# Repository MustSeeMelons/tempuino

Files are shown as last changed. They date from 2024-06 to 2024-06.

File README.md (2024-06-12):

# Infrared temprature thing

Portable! Battery powered! Rechargable!

Programable with a generic FTDI module. It even has a cutout.

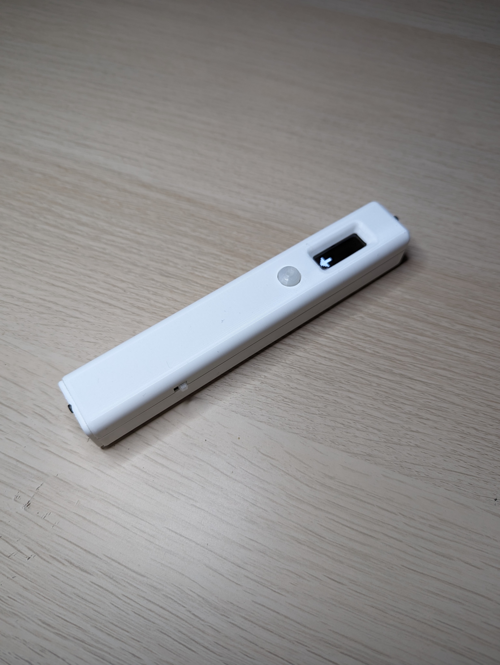
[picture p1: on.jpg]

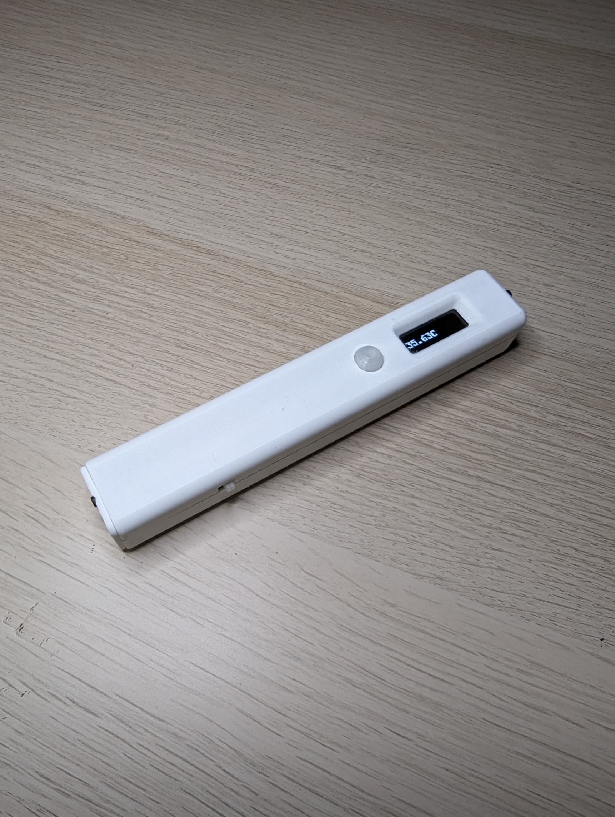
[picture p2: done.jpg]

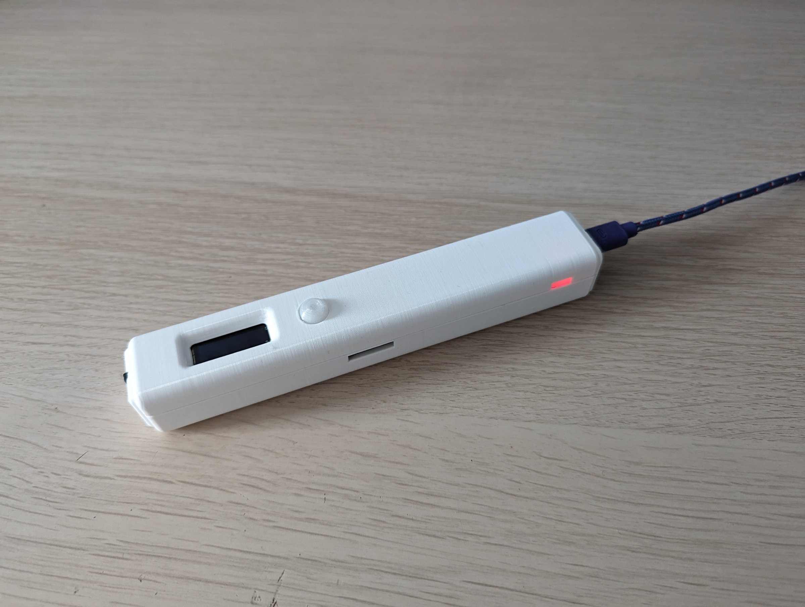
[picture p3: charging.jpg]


## Smol issue

Will not compile unless `.pio\libdeps\uno\ssd1306\src\ssd1306_hal\arduino\platform.cpp` is fixed by removing usages of `Wire1`. Just use `Wire` in their place. There was one more occurence.

## TODO

We might need to configure emissivity of the sensor. It defaults to 1.0.

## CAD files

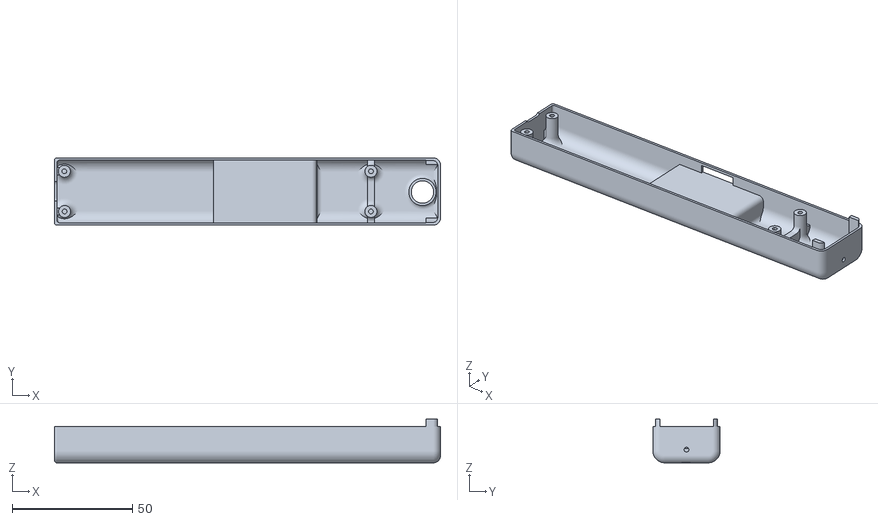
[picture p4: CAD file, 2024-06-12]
_cad/Bottom.stl
160.4 x 28.0 x 18.2

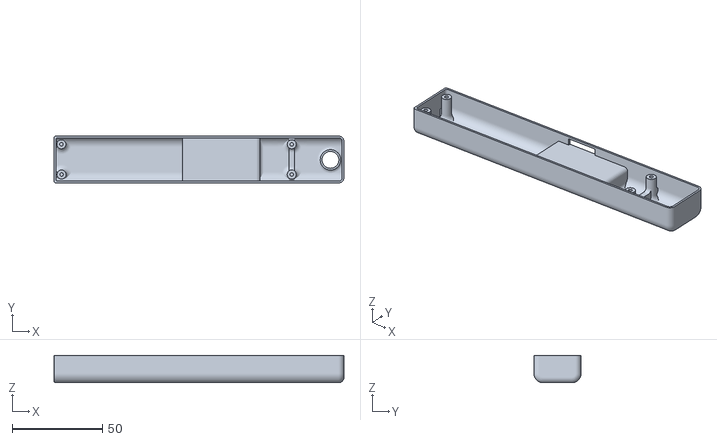
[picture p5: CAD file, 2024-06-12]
_ki_cad/output/Tempuino_Bottom.stl
160.4 x 26.0 x 15.2

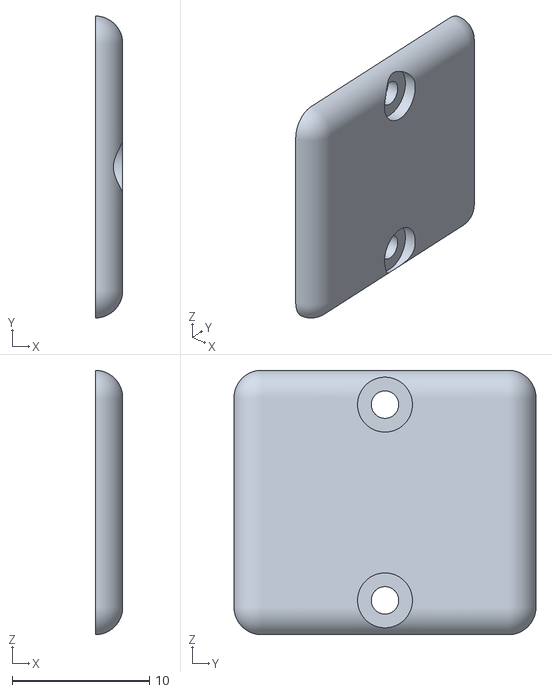
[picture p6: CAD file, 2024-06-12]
_cad/Top Thing.stl
2.00 x 22.0 x 19.3

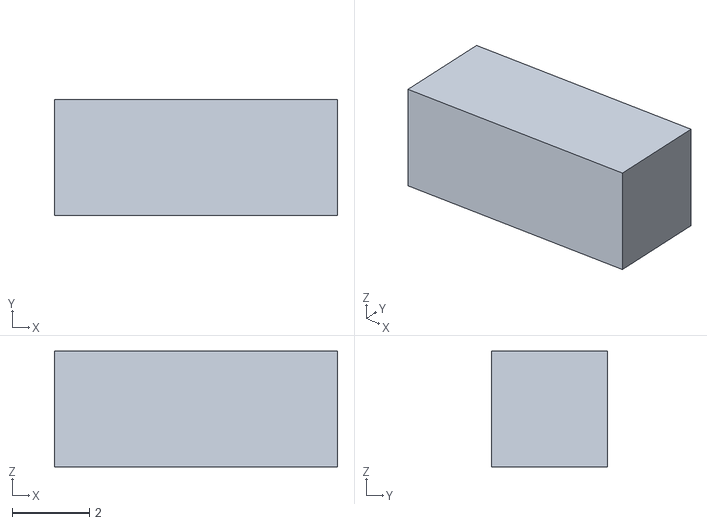
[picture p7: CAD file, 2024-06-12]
_cad/Battery LEDs.stl
7.33 x 3.00 x 3.00

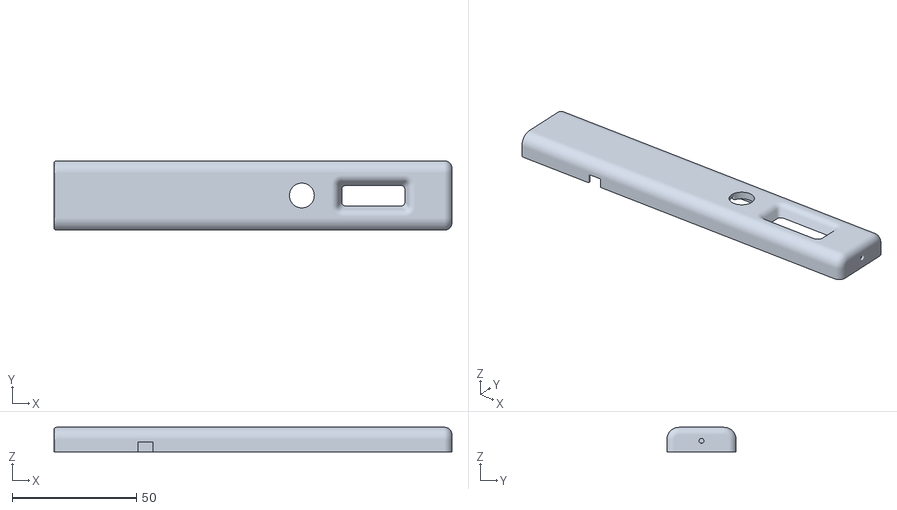
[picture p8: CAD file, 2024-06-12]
_cad/Top.stl
160.4 x 28.0 x 9.89

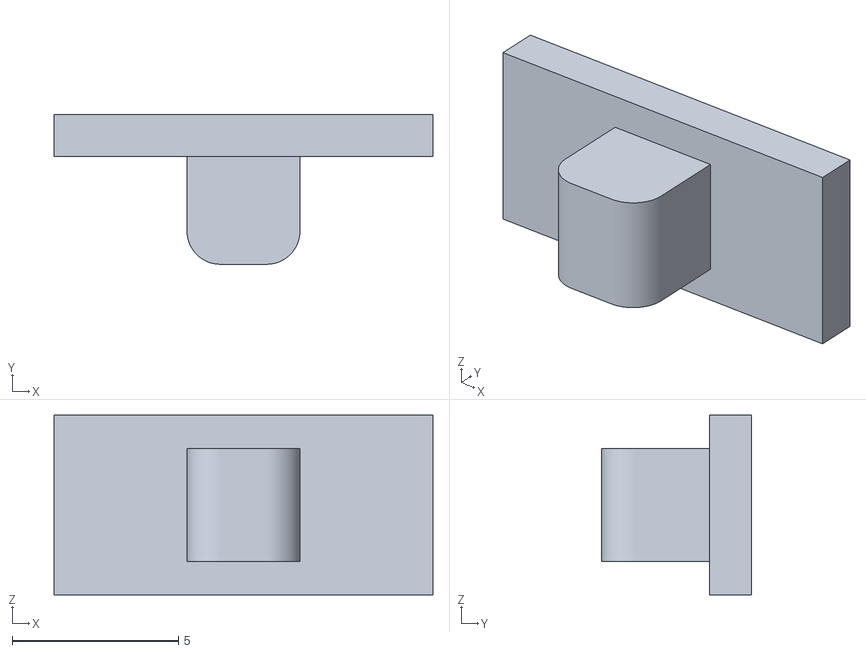
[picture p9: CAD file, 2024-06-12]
_cad/Power Switch.stl
11.4 x 4.50 x 5.40

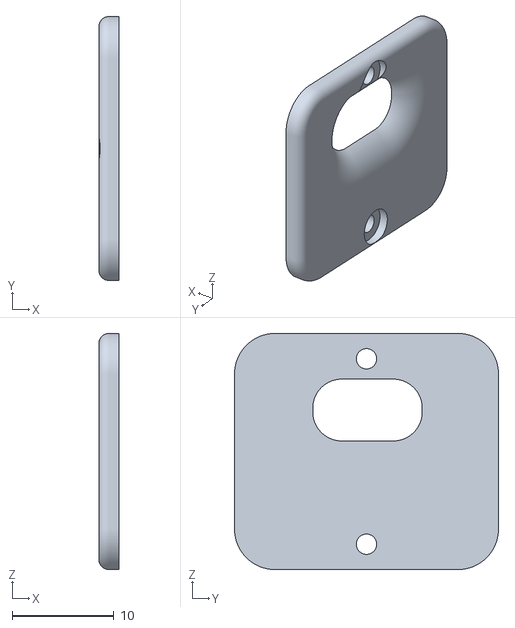
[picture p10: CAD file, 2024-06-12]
_cad/Bottom Thing.stl
2.00 x 26.0 x 23.3

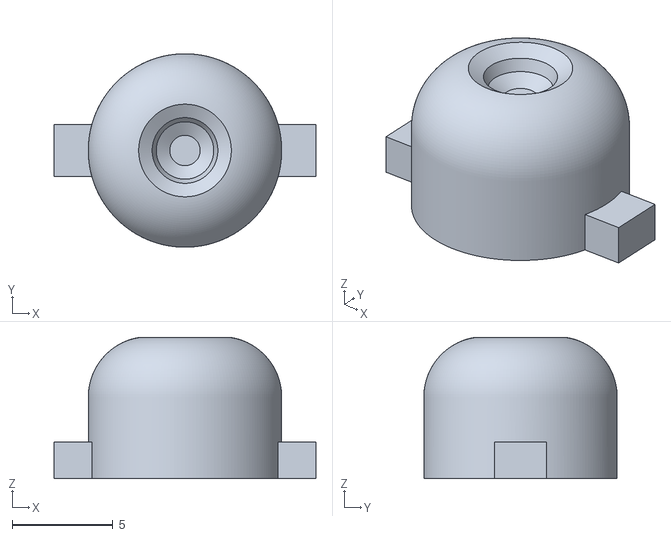
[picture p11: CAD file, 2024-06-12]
_cad/Action Button.stl
13.0 x 9.60 x 7.00

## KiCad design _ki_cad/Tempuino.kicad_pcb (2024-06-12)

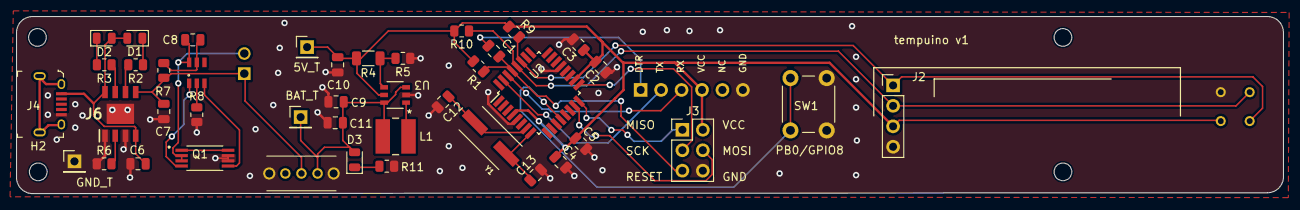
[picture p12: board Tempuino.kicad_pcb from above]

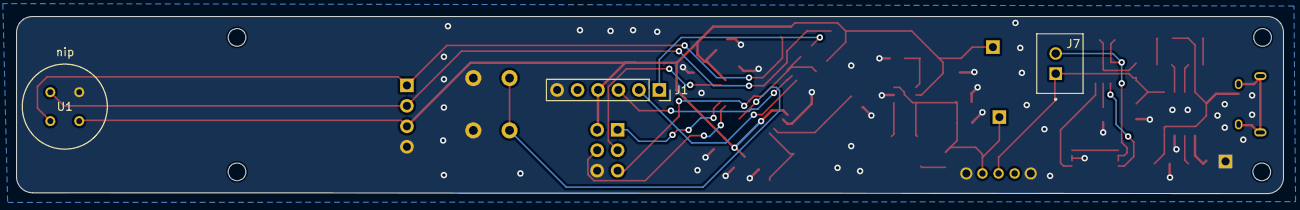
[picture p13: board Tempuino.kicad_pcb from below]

Board: 2 copper layers, 157.4 x 22.0 mm, 49 parts (3 on the bottom side), 30 nets.

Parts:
C1, C3, C4, C6, C8, C11: 100 nF; C_0805_2012Metric
C2, C5, C7, C9: 10 uF; C_0805_2012Metric
C10: 22 uF; C_0805_2012Metric
C12, C13: 20 pF; C_0805_2012Metric
D1, D2, D3: LED; LED_0805_2012Metric
H1, H2, H3, H4: MountingHole; MountingHole_2.2mm_M2
IC1: DW01A; SOT23-6
J1: Conn_01x06_Socket; PinSocket_1x06_P2.54mm_Vertical
J2: Conn_01x04_Pin; PinHeader_1x04_P2.54mm_Vertical
J3: Conn_02x03_Odd_Even; PinHeader_2x03_P2.54mm_Vertical
J4: 10118194-0001LF; USB_Micro_B_Female_10118194-0001LF
J5: GND_T; PinHeader_1x01_P2.54mm_Vertical
J6: TP4056; SOIC127P600X175-9N
J7: B2B-XH-A(LF)(SN); JST_B2B-XH-A(LF)(SN)
J8: B_T; PinHeader_1x01_P2.54mm_Vertical
J9: 5V_T; PinHeader_1x01_P2.54mm_Vertical
L1: 2.2 uH; IND_8357022_WRE
Q1: FS8205A; SOP65P640X120-8N
R1: 10K; R_0805_2012Metric
R2, R3, R6, R9, R10, R11: 1K; R_0805_2012Metric
R4: 900k Ohm; R_1206_3216Metric
R5: 100k Ohm; R_0805_2012Metric
R7: 100 Ohm; R_0805_2012Metric
R8: 1k Ohm; R_0805_2012Metric
SW1: SW_Push_Open; SW_PUSH_6mm
U1: MLX90614ESF-BCC-000-TU; MLX90614xCC_MEL
U2: ATmega328PB-A; TQFP-32_7x7mm_P0.8mm
U3: TLV61070ADBVR; SOT-23-6_DBV_TEX
U4: 1825232-1
Y1: ABLS7M-16.000MHZ-B-2-T; XTAL_ABLS7M-16.000MHZ-B-2-T

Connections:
/5V: C2.1, C3.1, C4.1, C5.1, C10.1, J1.4, J2.3, J3.2, J9.1, R1.2, R4.2, R9.2, R10.2, U1.3 (VDD), U2.4 (VCC), U2.18 (AVCC), U3.5 (VOUT)
/BAT_OUT: C9.1, C11.1, D3.2 (A), J8.1, L1.2, U3.3 (EN), U3.6 (VIN), U4.3
/CHARGE: J6.7 (~CHRG), R3.2
/DTR: C1.1, J1.1
/I2C_SCL: J2.2, R10.1, U1.1 (SCL/VZ), U2.28 (PC5)
/I2C_SDA: J2.1, R9.1, U1.2 (SDA/PWM), U2.27 (PC4)
/MISO_PB4: J3.1, U2.16 (PB4)
/MOSI_PB3: J3.4, U2.15 (PB3)
/PROG_SS: C1.2, J3.5, R1.1, U2.29 (~RESET/PC6)
/RX: J1.3, U2.30 (PD0)
/SCK_PB5: J3.3, U2.17 (PB5)
/STANDBY: J6.6 (~STDBY), R2.2
/TX: J1.2, U2.31 (PD1)
/VBUS: C6.1, D1.2 (A), D2.2 (A), J4.1, J6.4 (VCC4), J6.8 (CE)
GND: C2.2, C3.2, C4.2, C5.2, C6.2, C7.2, C9.2, C10.2, C11.2, C12.1, C13.2, J1.6, J2.4, J3.6, J4.5, J5.1, J6.1 (TEMP1), J6.3 (GND_3), J6.9 (EP), Q1.6, Q1.7, R5.1, R6.1, R8.1, R11.2, SW1.2 (B), U1.4 (VSS), U2.5 (GND), U2.21 (GND), U3.2 (GND), U4.GND, U4.GND1
unnamed: D1.1 (K), R2.1
unnamed: D2.1 (K), R3.1
unnamed: D3.1 (K), R11.1
unnamed: IC1.2 (CS), R8.2
unnamed: C8.2, IC1.6 (GND), J7.2, Q1.2, Q1.3
unnamed: IC1.3 (OC), Q1.5
unnamed: IC1.1 (OD), Q1.4
unnamed: C8.1, IC1.5 (VCC), R7.1
unnamed: C7.1, J6.5 (BAT), J7.1, R7.2, U4.2
unnamed: J6.2 (PROG2), R6.2
unnamed: SW1.1 (A), U2.12 (PB0)
unnamed: C12.2, U2.7 (XTAL1/PB6), Y1.2
unnamed: C13.1, U2.8 (XTAL2/PB7), Y1.1
unnamed: R4.1, R5.2, U3.4 (FB)
unnamed: L1.1, U3.1 (SW)

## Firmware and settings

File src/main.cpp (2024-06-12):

#include <stdint.h>
#include <Wire.h>
#include "ssd1306.h"
#include "mlx.h"
#include "Bounce2.h"
#include <stdbool.h>
#include "elapsedMillis.h"
// Some types for deeper library functions
#include "intf/ssd1306_interface.h"

// SSD1306 Driver 128X32 OLED
static const uint8_t d_width = 128;
static const uint8_t d_height = 32;

// References to display objects, for accessing some better functions
extern ssd1306_lcd_t ssd1306_lcd;
extern ssd1306_interface_t ssd1306_intf;

TwoWire *ourWire = &Wire;

static uint8_t action_btn_pin = 8;
static bool is_intro = true;
static Bounce bounce = Bounce();
static elapsedMillis idle_stamp;
static uint16_t idle_time = 30000; // ms

// Each byte is 8 vertical pixels
static uint8_t canvas[d_width][32 >> 3];

// Fill/unfill vars
static uint8_t anim_size = 8;
static uint8_t x_index = 0;
static uint8_t y_index = 0;
static bool is_fill = true;

// Arrow vars
static uint8_t idx = 0;        // Where do we start?
static uint8_t arrow_size = 8; // Same in h & w
static uint8_t arrow_scale = 4;
static bool is_forward = true;
static bool arrow_data[8][8] = {
    {0, 0, 0, 1, 0, 0, 0, 0},
    {0, 0, 1, 1, 0, 0, 0, 0},
    {0, 1, 1, 1, 0, 0, 0, 0},
    {1, 1, 1, 1, 1, 1, 1, 1},
    {1, 1, 1, 1, 1, 1, 1, 1},
    {0, 1, 1, 1, 0, 0, 0, 0},
    {0, 0, 1, 1, 0, 0, 0, 0},
    {0, 0, 0, 1, 0, 0, 0, 0},
};

void set_canvas_pixel(uint8_t x, uint8_t y)
{
  uint8_t p = y >> 3;  // Figure out which block it is
  uint8_t idx = y % 8; // Get bit index

  uint8_t value = 1 << idx; // Shuffle bit where we need it

  canvas[x][p] |= value; // Or bit into the new position
}

void clear_canvas_pixel(uint8_t x, uint8_t y)
{
  uint8_t p = y >> 3;  // Figure out which block it is
  uint8_t idx = y % 8; // Get bit index

  uint8_t value = ~(1 << idx); // Shuffle bit where we need it, and invert the result

  canvas[x][p] &= value; // And the abcent bit to clear
}

void setup()
{

  ssd1306_128x32_i2c_init();
  ssd1306_fillScreen(0x00);
  ssd1306_setFixedFont(ssd1306xled_font6x8);

  mlx_init();

  bounce.attach(action_btn_pin, INPUT_PULLUP);
  bounce.interval(50);
}

void tick_fill_anim()
{
  // Set current pixels
  for (uint8_t i = x_index; i < (x_index + anim_size); i++)
  {
    for (uint8_t j = y_index; j < (y_index + anim_size); j++)
    {
      if (is_fill)
      {
        set_canvas_pixel(i, j);
      }
      else
      {
        clear_canvas_pixel(i, j);
      }
    }
  }

  // Increment indexes
  x_index += anim_size;

  if (x_index == d_width)
  {
    x_index = 0;
    y_index += anim_size;
  }

  if (y_index == d_height)
  {
    y_index = 0;
    x_index = 0;

    is_fill = !is_fill;
  }
}

void tick_arrow_anim()
{
  // Clear old arrow
  for (uint8_t x = 0; x < arrow_size; x++)
  {
    for (uint8_t y = 0; y < arrow_size; y++)
    {
      for (uint8_t i = x * arrow_scale; i < x * arrow_scale + arrow_scale; i++)
      {
        for (uint8_t j = y * arrow_scale; j < y * arrow_scale + arrow_scale; j++)
        {
          if (is_forward)
          {
            clear_canvas_pixel(i + idx - 1, j);
          }
          else
          {
            clear_canvas_pixel(i + idx + 1, j);
          }
        }
      }
    }
  }

  // Switch arrow direction once we have traveled enough
  if (idx >= d_width * 0.1)
  {
    is_forward = false;
  }
  else if (idx == 0)
  {
    is_forward = true;
  }

  // Fill in the new arrow
  for (uint8_t x = 0; x < arrow_size; x++)
  {
    for (uint8_t y = 0; y < arrow_size; y++)
    {
      if (arrow_data[y][x] == true)
      {
        for (uint8_t i = x * arrow_scale; i < x * arrow_scale + arrow_scale; i++)
        {
          for (uint8_t j = y * arrow_scale; j < y * arrow_scale + arrow_scale; j++)
          {
            set_canvas_pixel(i + idx, j);
          }
        }
      }
    }
  }

  // XXX some interpolation with bounces would be nice, but at 8Mhz it is just too slow
  if (is_forward)
  {
    idx++;
  }
  else
  {
    idx--;
  }
}

/**
 * @brief Sends over the current state of the canvas to the screen.
 *
 */
void paint_lcd()
{
  ssd1306_lcd.set_block(0, 0, d_width);

  // Must iterate horizontaly as page flips vertically
  for (uint8_t y = 0; y < d_height >> 3; y++)
  {

    for (uint8_t x = 0; x < d_width; x++)
    {
      ssd1306_lcd.send_pixels1(canvas[x][y]);
    }

    ssd1306_lcd.next_page();
  }

  ssd1306_intf.stop();
}

void loop()
{

  if (is_intro)
  {
    tick_arrow_anim();
    paint_lcd();
  }

  bounce.update();

  if (bounce.read() == LOW)
  {
    idle_stamp = 0;

    if (is_intro)
    {
      is_intro = false;
    }
    // XXX we are not using ambient

    double ambientTemp = mlx_get_temp(MLX_TA);
    double objectTemp = mlx_get_temp(MLX_OBJ_1);

    // Must use the special function, sprintf can't format floats
    const uint8_t ambient_buffer[32] = {};
    char a_float_arr[6] = {};
    dtostrf(ambientTemp, 5, 2, a_float_arr);

    sprintf((char *)ambient_buffer, "Ambient: %sC, ", a_float_arr);

    const uint8_t object_buffer[32] = {};
    char o_float_arr[6] = {};
    dtostrf(objectTemp, 5, 2, o_float_arr);

    sprintf((char *)object_buffer, "%sC ", o_float_arr);

    ssd1306_fillScreen(0x00);
    ssd1306_printFixedN(0, 8, (char *)object_buffer, EFontStyle::STYLE_BOLD, EFontSize::FONT_SIZE_2X);

    delay(100);
  }

  // Show the animation after a while
  if (!is_intro && idle_stamp > idle_time)
  {
    is_intro = true;

    // Reset animation vars if any

    // Fill
    x_index = 0;
    y_index = 0;
    is_fill = true;

    // Arrow
    idx = 0; // Where do we start?
    is_forward = true;
  }
}

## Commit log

2024-05-15 Yeet Adafruit sensor lib
2024-06-12 Finished base funcionality
    [Action Button.stl, Battery LEDs.stl, Bottom Thing.stl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]
